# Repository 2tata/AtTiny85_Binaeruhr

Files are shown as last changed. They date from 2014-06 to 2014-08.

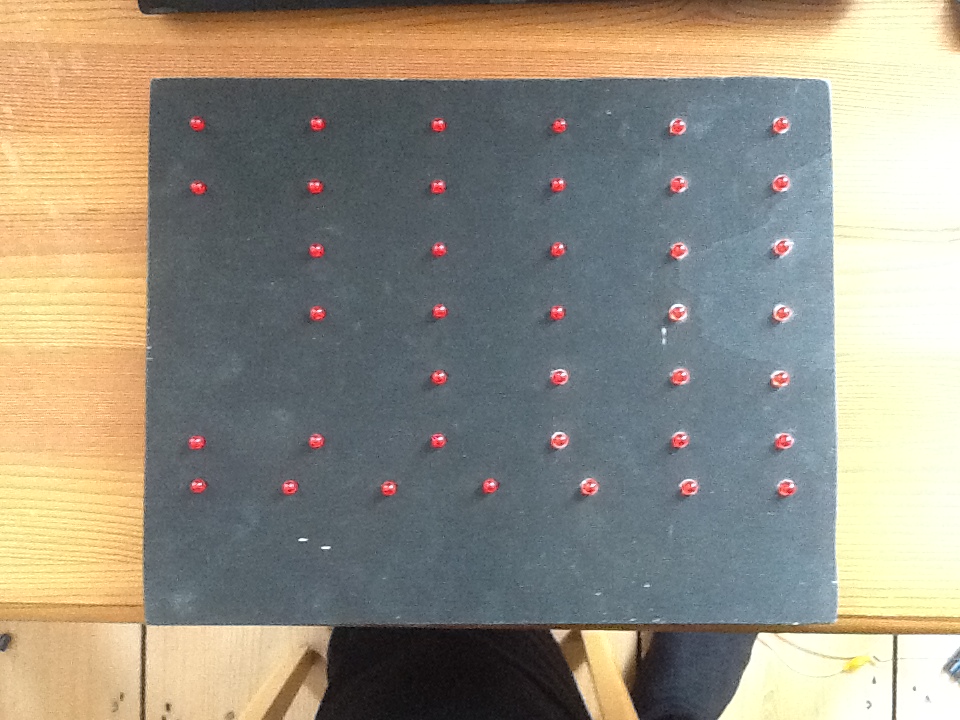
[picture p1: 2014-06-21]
Picture/IMG_0146.JPG

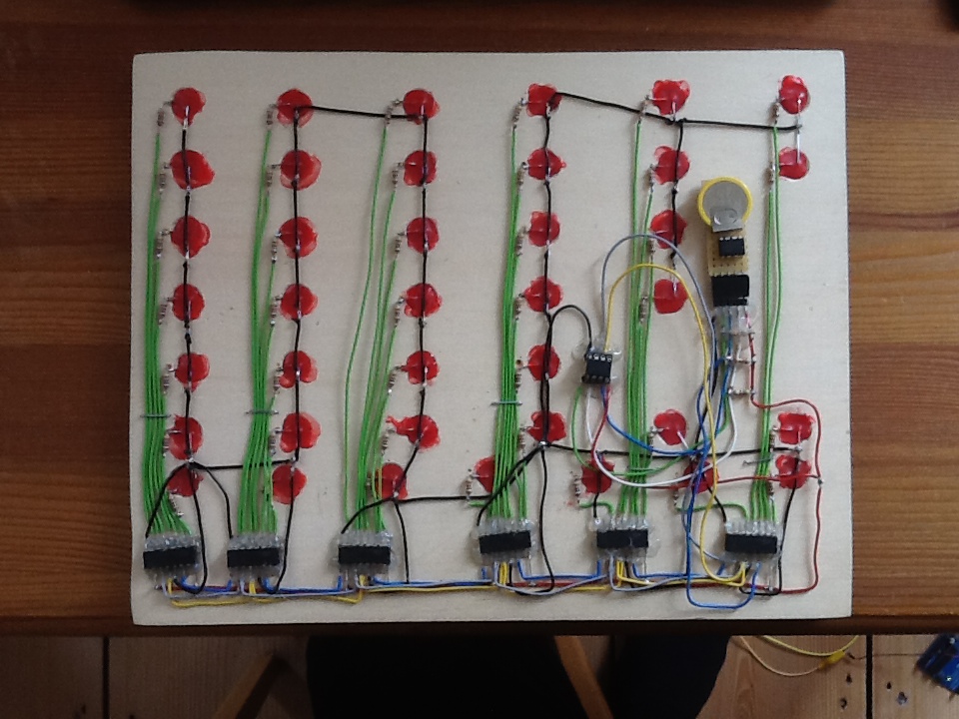
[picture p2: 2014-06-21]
Picture/IMG_0148.JPG

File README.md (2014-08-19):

AtTiny85_Binaeruhr
==================

A nice low coast LED binary clock.

For the configuration of the RTC use this --> https://github.com/2tata/Arduino_RTC-Configurator

I use for the ATtiny85 8MHz internal clockspeed besause 1MHz will not worke but I don´t know why.

If you have any question you can ask me.

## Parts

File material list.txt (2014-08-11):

	name		number		price

1. ATTINY 85-20 PU	  1		0,95€
2. 74HC 595		  6		1,50€
3. DS 1307		  1		2,15€
4. CR 2032P-H		  1		1,10€
5. 32,768 MS3V-12,5	  1		0,42€
6. LED 5MM RT		 40		2,40€
7. 150 ohm resistance	 40		4,12€
8. 4,7 k ohm resistance	  3		0,309€
9. insulated wire			0.70€
-----------------------------------------------
Total:					13,999€

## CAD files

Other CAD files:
cad/lasercutter.fcstd

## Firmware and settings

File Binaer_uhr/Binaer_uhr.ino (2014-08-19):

/*
#***********************************************
 #  Dateiname:  ..............  Binaer_uhr.ino  *
 #  Autor:  ..................  Jan-Tarek Butt  *
 #  Sprache:  .............................  C  *
 #  Dialekt:  .......................  Arduino  *
 #  Hardware:  .....................  AtTiny85  *
 #  Datum:  .......................  26.6.2013  *
 #***********************************************
 */

//start debugmode
//#define DEBUG
//#include <SoftwareSerial.h>

//include I2C library
#include <TinyWireM.h>
#include <USI_TWI_Master.h>

//define the day count per month
//                       {Ja,Fe,Mä,Ap,Ma,Jun,Jul,Au,Se,Ok,No,De}
const byte DaysInMonth[]={ 31,28,31,30,31,30,31,31,30,31,30,31};
//I2C adress of the RTC
const byte add=B01101000;
//Adressing of the LEDs in right range
//                              seconds                   minutes                  houers                    days                    months                  years                day of week
const byte BitTwiddling[]={47,39,31,22,13,3,0,0,    46,38,30,21,12,4,0,0,   45,37,29,20,10,0,0,0,    44,36,28,19,11,0,0,0,     43,35,27,18,0,0,0,0,    42,34,26,17,9,2,0,0,   41,33,25,23,14,5,1,0};
// RTC Pins
const byte Data=2;
const byte Clock=4;
const byte MClock=3;

// limit for RTC reading
byte ReadRound = 0;

byte SEC=0,MIN=0,HOUR=0,DAY=1,MONTH=1,YEAR=0,DAYOFWEEK=1;
boolean Sommerzeit=0;
byte *DataOut=(byte*) malloc(6);

int count=0;

#ifdef DEBUG
//Including serial library for debugging
#define rx -1
#define tx 3
SoftwareSerial mySerial(rx,tx);
#endif

void setup()
{
  ZeitEinlesen();

  pinMode(Data,OUTPUT);
  pinMode(Clock,OUTPUT);
  pinMode(MClock,OUTPUT);
  digitalWrite(Data,0);
  digitalWrite(Clock,0);
  digitalWrite(MClock,0);
#ifdef DEBUG
  mySerial.begin(9600);
#endif
}


void loop()
{
#ifdef DEBUG
  mySerial.println("Angezeigte zeit: ");
  mySerial.print("Date: ");
  mySerial.print(YEAR);
  mySerial.print("/");
  mySerial.print(MONTH);
  mySerial.print("/");
  mySerial.print(DAY);
  mySerial.print("  ");
  mySerial.print(HOUR);
  mySerial.print(":");
  mySerial.print(MIN);
  mySerial.print(":");
  mySerial.print(SEC);
  mySerial.print("  Sommerzeit:");
  mySerial.println(Sommerzeit);
  mySerial.println("");
#endif
  delay(1000);
  addOneSec();
  count++;
  if(count==62)
  {
    ZeitEinlesen();
    count=0;
  }
}

void addOneSec()
{
  SEC++;
  if(SEC==60)
  {
    MIN++;
    SEC=0;
  }
  if(MIN==60)
  {
    HOUR++;
    MIN=0;
    HOUR+=WiSo()-SoWi();
  }
  if(HOUR>23)
  {
    HOUR+=-24;
    DAY++;
    DAYOFWEEK=(DAYOFWEEK+1)%7;
  }
  if(DAY>DaysInMonth[MONTH-1])
  {
    if(MONTH!=2)
    {
      DAY=1;
      MONTH++;
    }
    else
    {
      if(YEAR%4)
      {
        DAY=1;
        MONTH++;
      }
      else
        if(DAY==30)
        {
          DAY=1;
          MONTH++;
        }
    }
  }
  if(MONTH==13)
  {
    YEAR++;
    MONTH=1;
  }
  writeOutTime();
}

byte SoWi()
{
  if((Sommerzeit) && (MONTH==10) && (DAY>24) && (DAYOFWEEK==6) && (HOUR==3))
  {
    Sommerzeit=false;
    return 1;
  }
  return 0;
}

byte WiSo()
{
  if((!Sommerzeit) && (MONTH==3) && (DAY>24) && (DAYOFWEEK==6) && (HOUR==2))
  {
    Sommerzeit=true;
    return 1;
  }
  return 0;
}

byte DoW_Gauss(word year,byte month,byte day)
{
  const byte m[]={0,0,3,2,5,0,3,5,1,4,6,2,4};
  byte y=(year%100)-(month==1 | month==2);
  byte c=(year/100)-(!(year%400));
  return (((day+m[month]+y+byte(y/4)+byte(c/4)-2*c+203-1)%7));
}

void SetSommerzeit()
{
  byte n;
  Sommerzeit=((MONTH>3) && (MONTH<10));
  if(MONTH==3)
  {
    for(n=31;DoW_Gauss(YEAR+2000,3,n)!=6;n--);
    Sommerzeit=(DAY>n);
    if(DAY==n)
    {
      Sommerzeit=HOUR>2;
    }
  }
  if(MONTH==10)
  {
    for(n=31;DoW_Gauss(YEAR+2000,10,n)!=6;n--);
    Sommerzeit=(DAY<n);
    if(DAY==n)
    {
      Sommerzeit=HOUR<2; 
    }
  }
}

byte BCD_decode(byte X,byte D)
{
  byte result;
  result =(X & (byte(1<<4)-1));
  result+=((X & ((byte(1<<D)-1)<<4))>>4)*10;
  return result;
}

void writeOutTime()
{
  byte c=0;
  byte dw=byte(1)<<DAYOFWEEK;
  bitchange(DataOut,c,SEC);
  c+=8;
  bitchange(DataOut,c,MIN);
  c+=8;
  bitchange(DataOut,c,HOUR);
  c+=8;
  bitchange(DataOut,c,DAY);
  c+=8;
  bitchange(DataOut,c,MONTH);
  c+=8;
  bitchange(DataOut,c,YEAR);
  c+=8;
  bitchange(DataOut,c,dw);
  shift(DataOut);
}

void bitchange(byte* Z,byte c,byte X)
{
  for(byte n=0;n<8;n++)
  {
    bitWrite(Z[BitTwiddling[c]/8],BitTwiddling[c]%8,bitRead(X,n));
    c++;
  }
}

void shift(byte* X)
{
  int n,m;
  digitalWrite(Clock,0);
  digitalWrite(MClock,0);
  for(m=5;m>-1;m--)
  {
    for(n=7;n>-1;n--)
    {
      digitalWrite(Data,(byte(X[m] & (byte(1)<<n)))>0);
      digitalWrite(Clock,1);
      digitalWrite(Clock,0);
    }
  }
  digitalWrite(MClock,1);
  digitalWrite(MClock,0);
}

void ZeitEinlesen()
{
  byte rSEC=0,rMIN=0,rHOUR=0,rDAY=1,rMONTH=1,rYEAR=0,rDAYOFWEEK=1;
  TinyWireM.begin();
  TinyWireM.beginTransmission(add);
  TinyWireM.send(0);
  TinyWireM.endTransmission();
  byte c;
  if (!TinyWireM.requestFrom(add, byte(7)))
  {
    c=TinyWireM.receive();
    rSEC=BCD_decode(c,3);

    c=TinyWireM.receive();
    rMIN=BCD_decode(c,3);

    c=TinyWireM.receive();
    rHOUR=BCD_decode(c,2);

    c=TinyWireM.receive();

    c=TinyWireM.receive();
    rDAY=BCD_decode(c,2);

    c=TinyWireM.receive();
    rMONTH=BCD_decode(c,1);

    c=TinyWireM.receive();
    rYEAR=BCD_decode(c,4);
    rDAYOFWEEK=DoW_Gauss(rYEAR+2000,rMONTH,rDAY);
#ifdef DEBUG
    mySerial.print("");
    mySerial.println("RTC zeit: ");
    mySerial.print("Date: ");
    mySerial.print(rYEAR);
    mySerial.print("/");
    mySerial.print(rMONTH);
    mySerial.print("/");
    mySerial.print(rDAY);
    mySerial.print("  ");
    mySerial.print(rHOUR);
    mySerial.print(":");
    mySerial.print(rMIN);
    mySerial.print(":");
    mySerial.print(rSEC);
    mySerial.print("  Sommerzeit:");
    mySerial.println(Sommerzeit);
    mySerial.println("");
#endif
    if(((rYEAR == YEAR || (rYEAR -1)==YEAR || (rYEAR +1)==YEAR) && (rMONTH == MONTH || (rMONTH -1)==MONTH || (rMONTH +1)==MONTH)) || (ReadRound <= 0 || ReadRound >= 4))
    {
      SEC=rSEC;
      MIN=rMIN;
      HOUR=rHOUR;
      DAY=rDAY;
      MONTH=rMONTH;
      YEAR=rYEAR;
      DAYOFWEEK=rDAYOFWEEK;
      ReadRound = 1;
    }
    else
    {
      ReadRound ++;
    }
    SetSommerzeit();
    HOUR+=Sommerzeit;
  }
}

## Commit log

2009-08-20 LED Posi. Layer
2014-06-20 add a Layout
    [Schaltplan.sch]
2014-06-21 convert all comments to english
    [Schaltplan.sch]
2014-06-21 add picture and material list
    [circuit diagram.sch]
2014-06-22 fix RTC read bug
    [Binaer_uhr.ino]
2014-08-11 recalculated materiallist
2016-12-22 Circuit diagram: add 7805 power supply
    [circuit diagram.sch]
2016-12-22 cad: add freecad layout for laser cutter
    [lasercutter.fcstd]
